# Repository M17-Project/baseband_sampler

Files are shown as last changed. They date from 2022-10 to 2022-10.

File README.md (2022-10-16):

# baseband_sampler
Arduino shield sized baseband sampler. It uses an STM32 F303RE Nucleo board and communicates over USB-UART (230400 baud, 8n1).

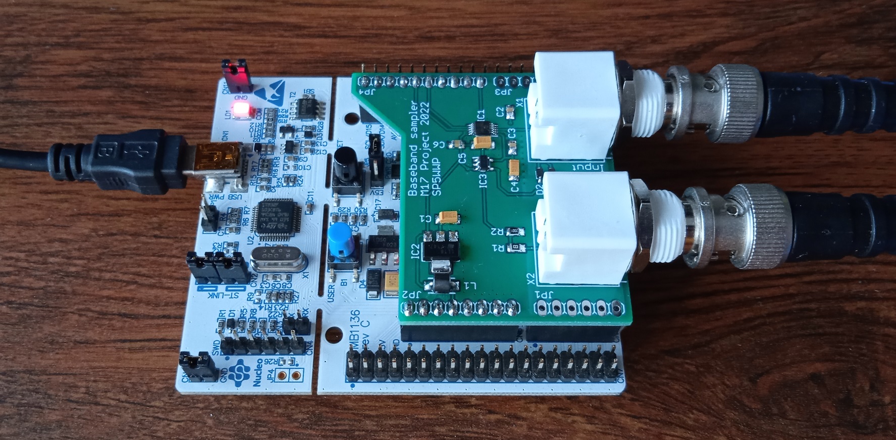
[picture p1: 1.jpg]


## What does it do?
The shield board contains:
- **MCP33131-10-E/MS** 16-bit 1Msps ADC converter,
- **LM4120AIM5-2.5** 2.5V reference,
- **LDL1117S18R** 1.8V low-drop voltage regulator.

The working principle is simple. After being interrogated by the host PC, by sending a single byte over UART, the device collects 19,200 samples of the signal presented at the `Input` port. The sampling trigger signal has to be provided by the user as a TTL signal at the `Trig` port. Every rising edge starts a conversion. After all samples are collected, all the data is sent to a PC as a string of `uint16_t` values.<br>
At the power-up, the ADC performs a calibration sequence taking approximately 500 ms. The blue button on the Nucleo can be used to force re-calibration when the user needs it (significant ambient temperature change etc.). Pressing the button initializes the same sequence.

## Contents
- `CubeIDE` - a complete CubeIDE project, this is where the source code is
- `EAGLE` - the schematic and PCB design files (EAGLE 7.7.0) along with zipped gerbers (tailored for JLCPCB).
- `Matlab` contains a demo Matlab application

## Demo Matlab application
Hit the `Start` button to send the acquisition command to the board. After a few seconds you should see the eye plot.

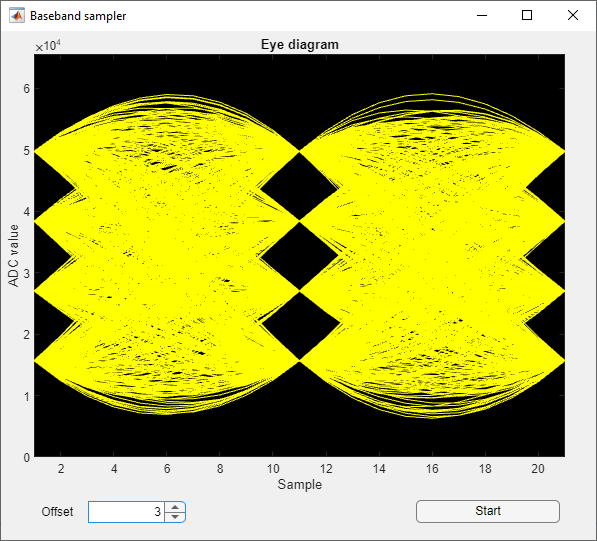
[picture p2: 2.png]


## References
- [MCP33111 family datasheet](https://ww1.microchip.com/downloads/en/DeviceDoc/MCP33131-MCP33121-MCP33111-Family-Data-Sheet-DS20006122A.pdf)

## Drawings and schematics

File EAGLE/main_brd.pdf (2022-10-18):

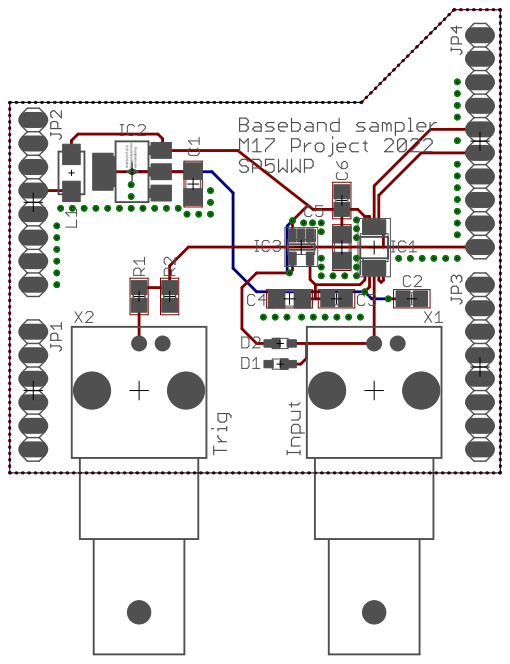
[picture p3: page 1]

direction of pcb transportation for wavesoldering

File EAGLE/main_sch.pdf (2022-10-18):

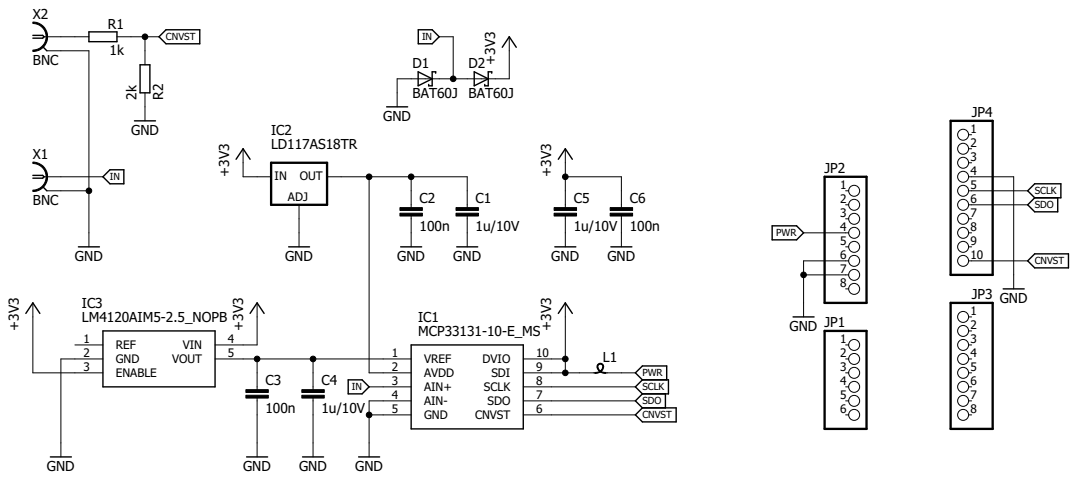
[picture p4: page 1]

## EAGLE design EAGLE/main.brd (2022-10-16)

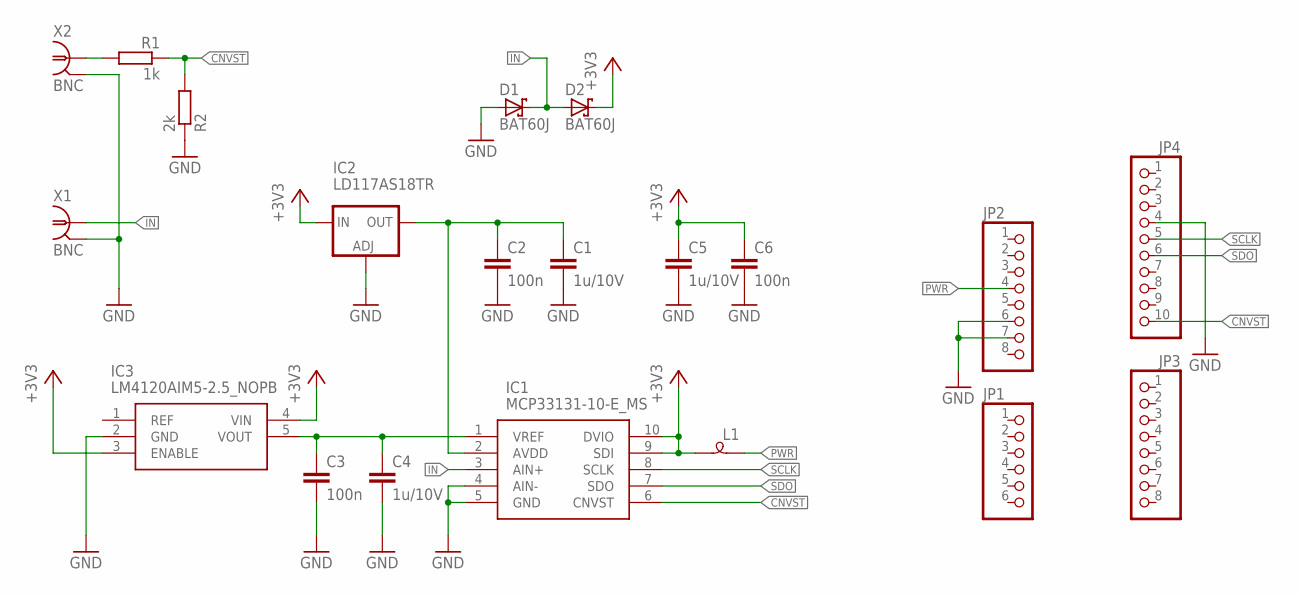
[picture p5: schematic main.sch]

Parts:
C1, C4, C5: 1u/10V; C1206
C2, C3, C6: 100n; C0805
D1, D2: BAT60J; SOD323_ST
IC1: MCP33131-10-E_MS; SOP50P490X110-10N
IC2: LD117AS18TR; SOT223
IC3: LM4120AIM5-2.5_NOPB; SOT95P280X145-5N
JP1: PINHD-1X6; 1X06
JP2, JP3: PINHD-1X8; 1X08
JP4: PINHD-1X10; 1X10
L1: SM-B5
R1: 1k; R0805
R2: 2k; R0805
X1, X2: BNC; AMP_227161

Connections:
+3V3: C5.1, C6.1, D2.C, IC1.9 (SDI), IC1.10 (DVIO), IC2.3 (IN), IC3.3 (ENABLE), IC3.4 (VIN), L1.2
CNVST: IC1.6 (CNVST), JP4.10, R1.1, R2.2
GND: C1.2, C2.2, C3.2, C4.2, C5.2, C6.2, D1.A, IC1.4 (AIN-), IC1.5 (GND), IC2.1 (ADJ), IC3.2 (GND), JP2.6, JP2.7, JP4.4, R2.1, X1.2, X2.2
IN: D1.C, D2.A, IC1.3 (AIN+), X1.1
unnamed: C3.1, C4.1, IC1.1 (VREF), IC3.5 (VOUT)
unnamed: C1.1, C2.1, IC1.2 (AVDD), IC2.4 (OUT)
unnamed: R1.2, X2.1
PWR: JP2.4, L1.1
SCLK: IC1.8 (SCLK), JP4.5
SDO: IC1.7 (SDO), JP4.6

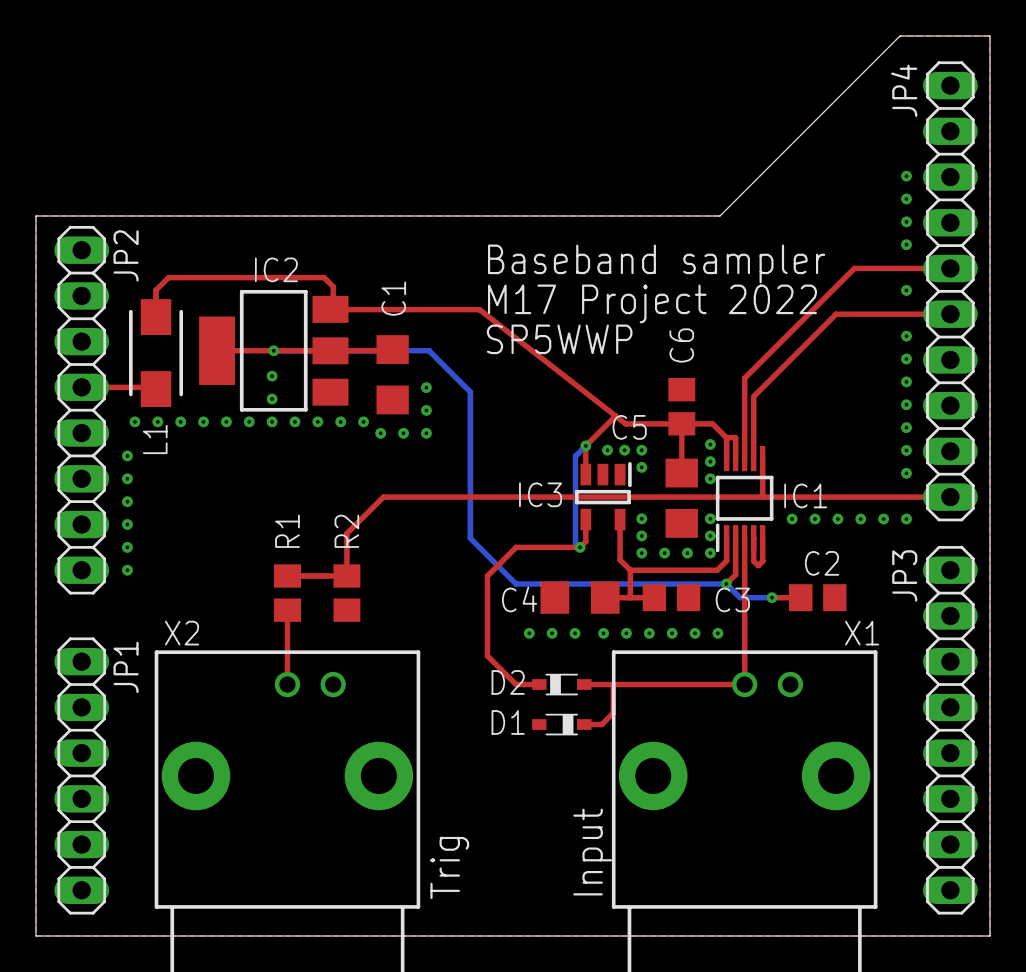
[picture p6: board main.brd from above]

Board: 2 copper layers, 53.0 x 50.0 mm, 20 parts (0 on the bottom side), 10 nets.

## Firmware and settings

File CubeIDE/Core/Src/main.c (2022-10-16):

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
/* Includes ------------------------------------------------------------------*/
#include "main.h"

/* USER CODE BEGIN Includes */
#include <string.h>
/* USER CODE END Includes */

/* USER CODE BEGIN PD */
#define NUM_SAMPLES		19200
/* USER CODE END PD */

SPI_HandleTypeDef hspi1;

UART_HandleTypeDef huart2;

/* USER CODE BEGIN PV */
uint8_t cal[128];
uint8_t val[2];

uint16_t data[NUM_SAMPLES];

uint8_t cal_pending=0;
uint8_t sampling=0;
uint8_t ready=0;
volatile uint8_t done=0;
uint32_t cnt=0;
/* USER CODE END PV */

void SystemClock_Config(void);
static void MX_GPIO_Init(void);
static void MX_USART2_UART_Init(void);
static void MX_SPI1_Init(void);
/* USER CODE BEGIN 0 */
void HAL_GPIO_EXTI_Callback(uint16_t GPIO_Pin)
{
	//CONVST
	if(HAL_GPIO_ReadPin(CONVST_GPIO_Port, CONVST_Pin)==0 && sampling && ready)
	{
		HAL_SPI_Receive(&hspi1, val, 2, 1);
		data[cnt]=(val[1]<<8)|val[0];
		cnt++;

		if(cnt>=NUM_SAMPLES)
		{
			sampling=0;
			cnt=0;
			done=1;
		}
	}

	//blue button
	else if(HAL_GPIO_ReadPin(BTN_GPIO_Port, BTN_Pin)==0)
	{
		cal_pending=1;
		//sampling=1;
	}
}

void HAL_UART_RxCpltCallback(UART_HandleTypeDef *huart)
{
	if(sampling==0 && done==0 && cnt==0)
		sampling=1;
	HAL_UART_Receive_IT(&huart2, cal, 1); //destination doesnt matter
}
/* USER CODE END 0 */

/**
  * @brief  The application entry point.
  * @retval int
  */
int main(void)
{
  /* MCU Configuration--------------------------------------------------------*/

  /* Reset of all peripherals, Initializes the Flash interface and the Systick. */
  HAL_Init();

  /* Configure the system clock */
  SystemClock_Config();

  /* Initialize all configured peripherals */
  MX_GPIO_Init();
  MX_USART2_UART_Init();
  MX_SPI1_Init();
  /* USER CODE BEGIN 2 */
  memset((uint8_t*)cal, 0xAA, 128);
  cal_pending=1;
  HAL_Delay(250);
  HAL_UART_Receive_IT(&huart2, cal, 1); //destination doesnt matter

  /* USER CODE END 2 */

  /* Infinite loop */
  /* USER CODE BEGIN WHILE */
  while (1)
  {
	  if(cal_pending)
	  {
		  HAL_SPI_Transmit(&hspi1, cal, 128, 1000);
		  HAL_Delay(750);

		  cal_pending=0;
		  ready=1;
	  }
	  if(done)
	  {
		  HAL_UART_Transmit(&huart2, (uint8_t*)data, NUM_SAMPLES*2, 3000);
		  done=0;
	  }
    /* USER CODE END WHILE */

    /* USER CODE BEGIN 3 */
  }
  /* USER CODE END 3 */
}

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


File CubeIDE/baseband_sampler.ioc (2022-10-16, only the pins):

Mcu.UserName=STM32F303RETx
PA13.GPIO_Label=TMS
PA13.Signal=SYS_JTMS-SWDIO
PA14.GPIO_Label=TCK
PA14.Signal=SYS_JTCK-SWCLK
PA2.GPIO_Label=USART_TX
PA2.Signal=USART2_TX
PA3.GPIO_Label=USART_RX
PA3.Signal=USART2_RX
PA5.Signal=SPI1_SCK
PA6.Signal=SPI1_MISO
PA7.Signal=SPI1_MOSI
PA9.GPIO_Label=CONVST
PA9.Signal=GPXTI9
PC13.GPIO_Label=BTN
PC13.Signal=GPXTI13
PC14-OSC32_IN.Signal=RCC_OSC32_IN
PC15-OSC32_OUT.Signal=RCC_OSC32_OUT
PF0-OSC_IN.Signal=RCC_OSC_IN

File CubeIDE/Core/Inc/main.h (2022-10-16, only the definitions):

#define BTN_Pin GPIO_PIN_13
#define BTN_GPIO_Port GPIOC
#define BTN_EXTI_IRQn EXTI15_10_IRQn
#define USART_TX_Pin GPIO_PIN_2
#define USART_TX_GPIO_Port GPIOA
#define USART_RX_Pin GPIO_PIN_3
#define USART_RX_GPIO_Port GPIOA
#define CONVST_Pin GPIO_PIN_9
#define CONVST_GPIO_Port GPIOA
#define CONVST_EXTI_IRQn EXTI9_5_IRQn
#define TMS_Pin GPIO_PIN_13
#define TMS_GPIO_Port GPIOA
#define TCK_Pin GPIO_PIN_14
#define TCK_GPIO_Port GPIOA

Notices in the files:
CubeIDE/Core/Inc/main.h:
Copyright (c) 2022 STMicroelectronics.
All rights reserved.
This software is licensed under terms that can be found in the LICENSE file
